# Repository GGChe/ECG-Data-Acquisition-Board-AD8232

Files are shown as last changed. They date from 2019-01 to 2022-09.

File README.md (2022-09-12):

# ECG Data Acquisition Device
In this project you can find how to fabricate an ECG data acquisition board using AD8232 analog front end. The device enables the measuring of heart's electrical signal generated during the systole and diastole of atriums and ventricles by using electrodes. After obtaining that data, a signal processing algorithm based on Pan-Tompkins method in order to obtain the peak rate.

## Getting Started

These instructions will get you a copy of the project up and running on your local machine for development and testing purposes. See deployment for notes on how to deploy the project on a live system.

### Prerequisites

Components required:
- Arduino
- ECG Electrodes
- Print your PCBs
- SMD resistors:
  - 1x100Kohm
  - 3x1Mohm
  - 6x10Kohm
  - 2x180Kohm
  - 1x360Kohm
  - 1x1Kohm
  - 1x1.4Mohm
  - 1x10Kohm
  - 2x0ohm
- Capacitors:
  - 1x0.01uF
  - 2x0.33uF
  - 1x1500pF
  - 1x1000pF
  - 2x0.01uF
- Audio Jack SMT 3.5mm
- LED standard SMD
AD8232 SMD ECG front end

You will need to install some of the following softwares:
- Eagle (or any other PCB CAD software)
- MATLAB for the code
- SolidWorks for the Case

### Installing

Download the files, print the PCB and solder it. The final device should look like this:


## Running the tests

To run a test, you would need to download the code provided for arduino and upload it to the microcontroller. Then, connect the second board in the correct orientation and finally, connect the electrodes to the chest in the Einthoven Triangle. That's the best configuration for obtaining the high quality signal. However, do not worry about the microshocks because the current used in the system is not strong enough to produce any organic failure in the patient's body.

## Authors

* [Gabriel Galeote Checa](https://github.com/GGChe)

Any inquiry of consulting, please write an issue or send me a message to ggaleotecheca@gmail.com

## License

Creative Commons license

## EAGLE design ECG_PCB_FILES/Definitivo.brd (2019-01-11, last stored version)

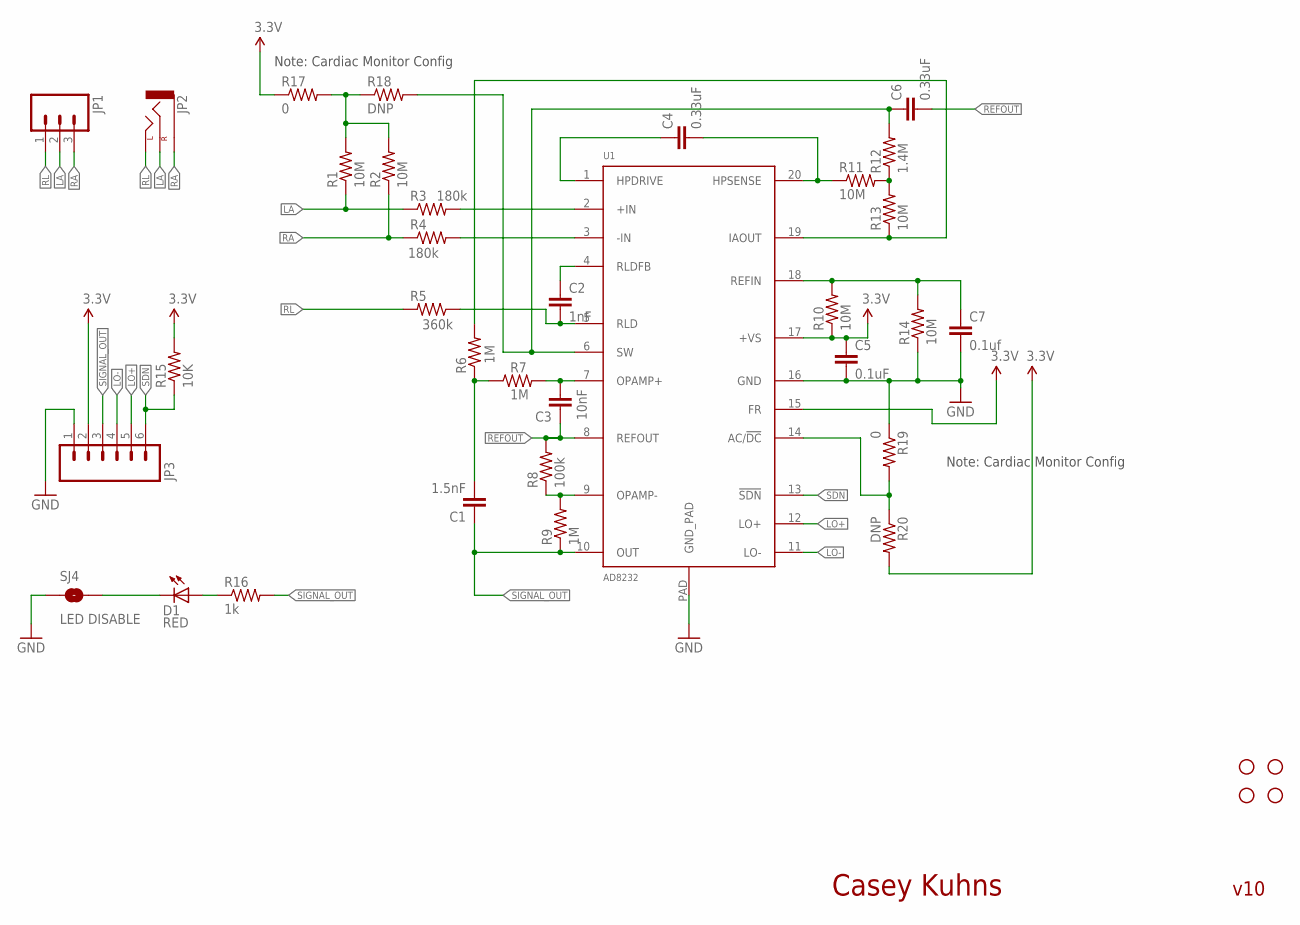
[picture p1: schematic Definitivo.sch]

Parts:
C1: 1.5nF; 0603-CAP
C2: 1nF; 0603-CAP
C3: 10nF; 0603-CAP
C4, C6: 0.33uF; 0805
C5: 0.1uF; 0603-CAP
C7: 0.1uf; 0603-CAP
D1: RED; LED-0603
JP1: M03PTH; 1X03
JP2: AUDIO-JACKSMD2; AUDIO-JACK-3.5MM-SMD
JP3: M06SIP; 1X06
R1, R2, R10, R11, R13, R14: 10M; 0603-RES
R3, R4: 180k; 0603-RES
R5: 360k; 0603-RES
R6, R7, R9: 1M; 0603-RES
R8: 100k; 0603-RES
R12: 1.4M; 0603-RES
R15: 10K; 0603-RES
R16: 1k; 0603-RES
R17, R19: 0; 0603
R18, R20: DNP; 0603
SJ4: LED DISABLE; SJ_2S-TRACE
STANDOFF1, STANDOFF2, STANDOFF3, STANDOFF4: STAND-OFF
U1: AD8232; LFCSP_20

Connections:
3.3V: C5.1, JP3.2, R10.1, R15.2, R17.1, R20.2, U1.15 (FR), U1.17 (+VS)
GND: C5.2, C7.2, JP3.1, R14.1, R19.1, SJ4.1, U1.16 (GND), U1.PAD (GND_PAD)
LA: JP1.2, JP2.RING (RIGHT), R1.1, R3.1
LO+: JP3.5, U1.12 (LO+)
LO-: JP3.4, U1.11 (LO-)
unnamed: R3.2, U1.2 (+IN)
unnamed: R4.2, U1.3 (-IN)
unnamed: C3.2, R7.2, U1.7 (OPAMP+)
unnamed: C4.2, R11.1, U1.20 (HPSENSE)
unnamed: C7.1, R10.2, R14.2, U1.18 (REFIN)
unnamed: D1.A, R16.1
unnamed: R8.1, R9.2, U1.9 (OPAMP-)
unnamed: R6.2, R13.1, U1.19 (IAOUT)
unnamed: C1.2, R6.1, R7.1
unnamed: D1.C, SJ4.2
unnamed: R19.2, R20.1, U1.14 (AC/!DC)
unnamed: C4.1, U1.1 (HPDRIVE)
unnamed: R11.2, R12.1, R13.2
unnamed: C6.1, R12.2, R18.2, U1.6 (SW)
unnamed: C2.1, U1.4 (RLDFB)
unnamed: C2.2, R5.1, U1.5 (RLD)
unnamed: R1.2, R2.2, R17.2, R18.1
RA: JP1.3, JP2.SLEEVE, R2.1, R4.1
REFOUT: C3.1, C6.2, R8.2, U1.8 (REFOUT)
RL: JP1.1, JP2.TIP (LEFT), R5.2
SDN: JP3.6, R15.1, U1.13 (!SDN)
SIGNAL_OUT: C1.1, JP3.3, R9.1, R16.2, U1.10 (OUT)

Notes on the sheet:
Casey Kuhns
v10
Note: Cardiac Monitor Config

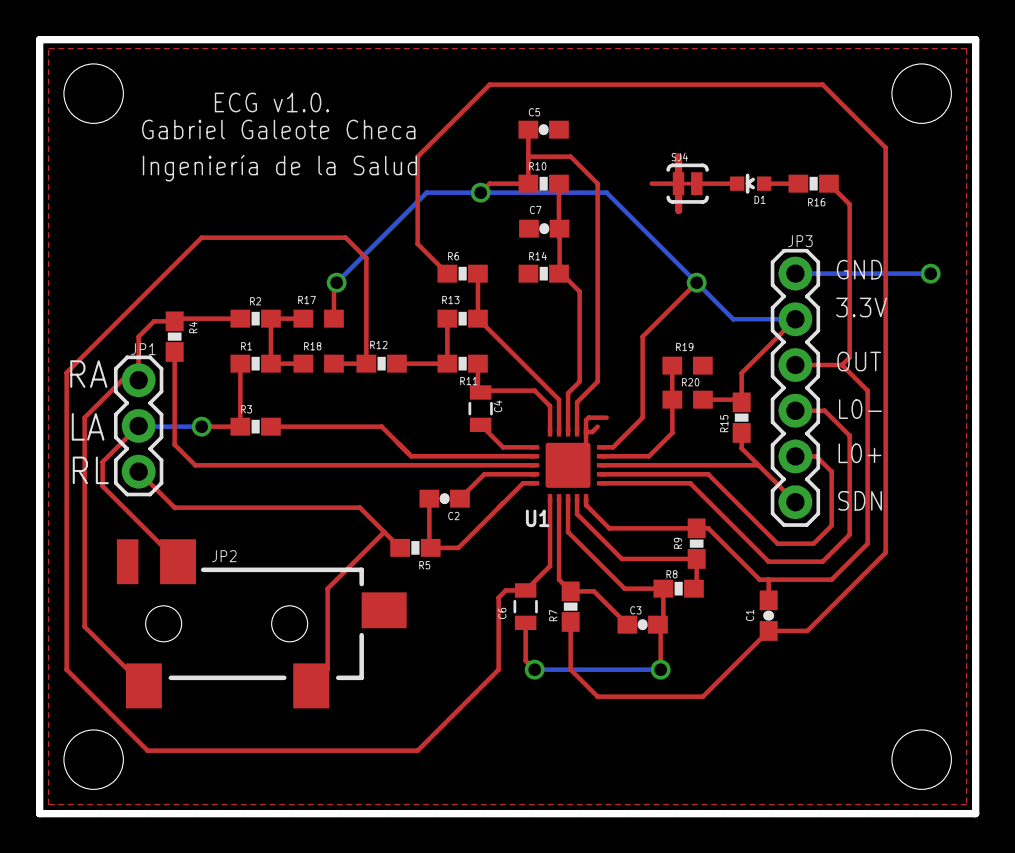
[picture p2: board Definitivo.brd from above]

Board: 2 copper layers, 52.0 x 43.0 mm, 37 parts (0 on the bottom side), 27 nets.

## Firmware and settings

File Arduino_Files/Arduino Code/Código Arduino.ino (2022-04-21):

/******************************************************************************
  Project: Arduino embedded code
  Author: Gabriel Galeote Checa
  Summary of connections:
    - Analog Inputs on AN 0, 1, and 2
    - SD card communicated through SPI bus as follows:
      - MOSI - pin 51
      - MISO - pin 50
      - CLK - pin 52
      - CS - pin 53

******************************************************************************/
#include <SPI.h>
#include <SD.h>

const int chipSelect = 53;
int read = 0;
File dataFile;

void setup() {
  // Initialize IO
  pinMode(10, INPUT); // Setup for leads off detection LO +
  pinMode(11, INPUT); // Setup for leads off detection LO -
  pinMode(chipSelect, OUTPUT);
  // Serial communication set to 9600 bauds, standard value.
  Serial.begin(9600);
  while (!Serial) {
    ; // wait for serial port to connect. Needed for native USB port only
  }

  if (!SD.begin(chipSelect)) {
    Serial.println("Card failed, or not present");
    return;
  }
  Serial.println("card initialized.");
}


void loop() {
  // Start first reading from the data acquisition board
  if ((digitalRead(10) == 1) || (digitalRead(11) == 1)) {
    Serial.println('!');
  }
  else {
    dataFile = SD.open("ECG.txt", FILE_WRITE);
    read = analogRead(A0);
    // if the file is available, write to it:
    if (dataFile) {
      dataFile.print(String(read));
      dataFile.print(" ");
      dataFile.close();
      // print to the serial port too:
      Serial.println(read);
    }
    // if the file isn't open, pop up an error:
    else {
      Serial.println("error opening ECG.txt");
    }
  }

}

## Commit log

2019-01-11 All the schematic and PCB design of the project.
    That schematic was made with the software Eagle.
    [Definitivo.brd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]
2019-01-11 Create Arduino_Files
2020-05-02 update arduino
2022-04-21 refactor project code
    [Definitivo.brd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]

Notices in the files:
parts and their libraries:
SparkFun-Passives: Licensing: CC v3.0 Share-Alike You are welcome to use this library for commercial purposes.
